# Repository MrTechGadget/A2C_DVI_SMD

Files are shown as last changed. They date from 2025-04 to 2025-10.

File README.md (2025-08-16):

# A2CDVI_SMD

This is a project for a digital DVI/HDMI video cards for Apple IIc or IIc+. It directly produces a digital video stream from the Apple IIc's digital video output connector. The signal is output via an HDMI connector, connecting the Apple IIc to modern displays with HDMI (or DVI) inputs. No more analog signal conversion required.

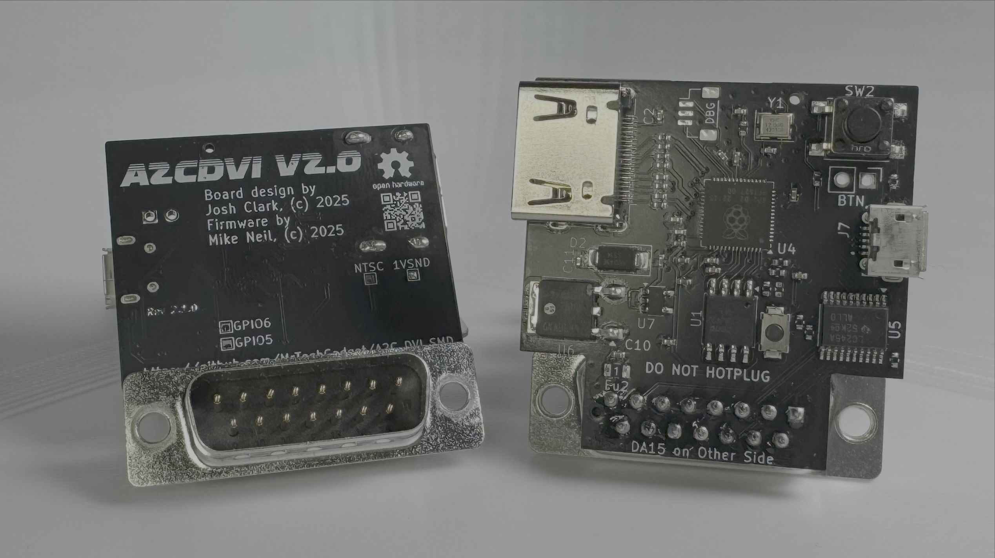
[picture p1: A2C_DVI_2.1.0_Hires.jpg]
A2CDVI v2.1.0 Board


## BACKGROUND
### Mike Neil's [Inspiration](https://github.com/FarLeftLane/A2C_DVI_Board)
> I have been working on a project using an ESP32-C6 to take the digital video signals from the Apple IIc DB15 video connector and allow remote viewing of the screen on a PC (watch this account for the ViewIIc plans).  The circuit design was pretty simple, a DB15 connector, a 74VLC245 for level conversion (5V to 3.3V) and a ESP32-C6 module. It occured to me that I could take those same Apple IIc signals and using the picoDVI libraries create a IIc to HDMI solution using an RP2040 or RP2350 (Raspberry Pi Pico). This is the same HW that is on an A2DVI card for a slotted Apple II (RP2040 and 245's). The Protype takes the A2DVI card out of the machine and instead of connecting to Apple II bus signals (address, data, etc), we feed the Apple IIc digital video signals into the cards pins and use custom firmware to recreate the display out to HDMI.

## HARDWARE
### Protoype

My first version was designed from Mike's schematic and mapping those through the the needed components found on the A2DVI card itself. It utilized a Raspberry Pi Pico device for simplicity, but the overall size was too big and it blocked access to the composite video

### Version 2

Inspired by the working prototype, I decided I could make it MUCH smaller by implementing the RP2040 directly on the board. 

### Version 2.5

Fixed compatibility issues with some HDTVs and added hardware support for Mike Neil's latest firmware features!

## Availability

This card is available for purchase in the US for $35 plus shipping on my Tindie Store [MrTechGadget's Gadgets](https://www.tindie.com/products/mrtechgadget/a2cdvi/)

## Flashing Firmware
The latest firmware can be found on Mike Neil's [A2C_DVI_Firmware repo](https://github.com/FarLeftLane/A2C_DVI_Firmware/tree/master/Releases)

To load the firmware use a microUSB cable to your PC/Mac with the A2CDVI card plugged into the Apple IIc. It is the exact same process as flashing a Raspberry Pi Pico. There is a small BOOTSEL button in the middle of the board close to the DA15 connector, above the word HOTPLUG.  Hold that button down, and while holding it, plug the USB cable into your PC/Mac.  You should see a volume appear on the PC/Mac.  Copy the "A2C_DVI_v1.7.6.uf2" file to this volume and the card should update and reboot.   If you have a HDMI monitor attached to the card, you should see the A2C_DVI splash screen.  Unplug the card from USB.  Never Hotplug the DA15 connector to the Apple IIc.

**SPECIAL THANKS**

- Mike Neil ( https://github.com/FarLeftLane/ )
- Ralle Palaveev ( https://github.com/rallepalaveev/A2DVI )
- Thorsten Brehm ( https://github.com/ThorstenBr/A2DVI-Firmware )
- David Kuder ( https://github.com/V2RetroComputing/analog )

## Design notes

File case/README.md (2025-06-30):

# Case for A2CDVI v2.0

Thanks to Javier Rivera at [8bitstuff.com](https://www.8bitstuff.com/) for this 3D print case design! Check out and purchase his wonderful creations there!

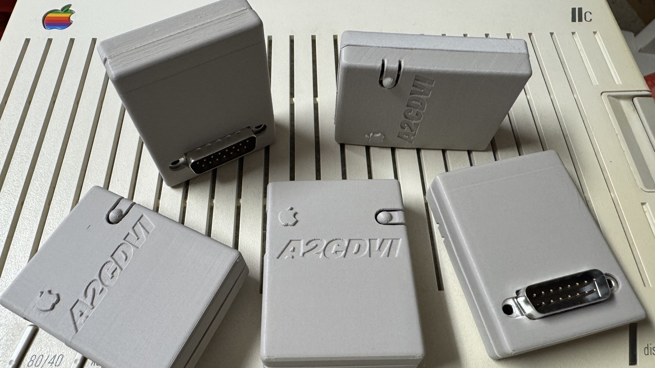
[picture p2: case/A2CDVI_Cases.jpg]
A2CDVI Cases


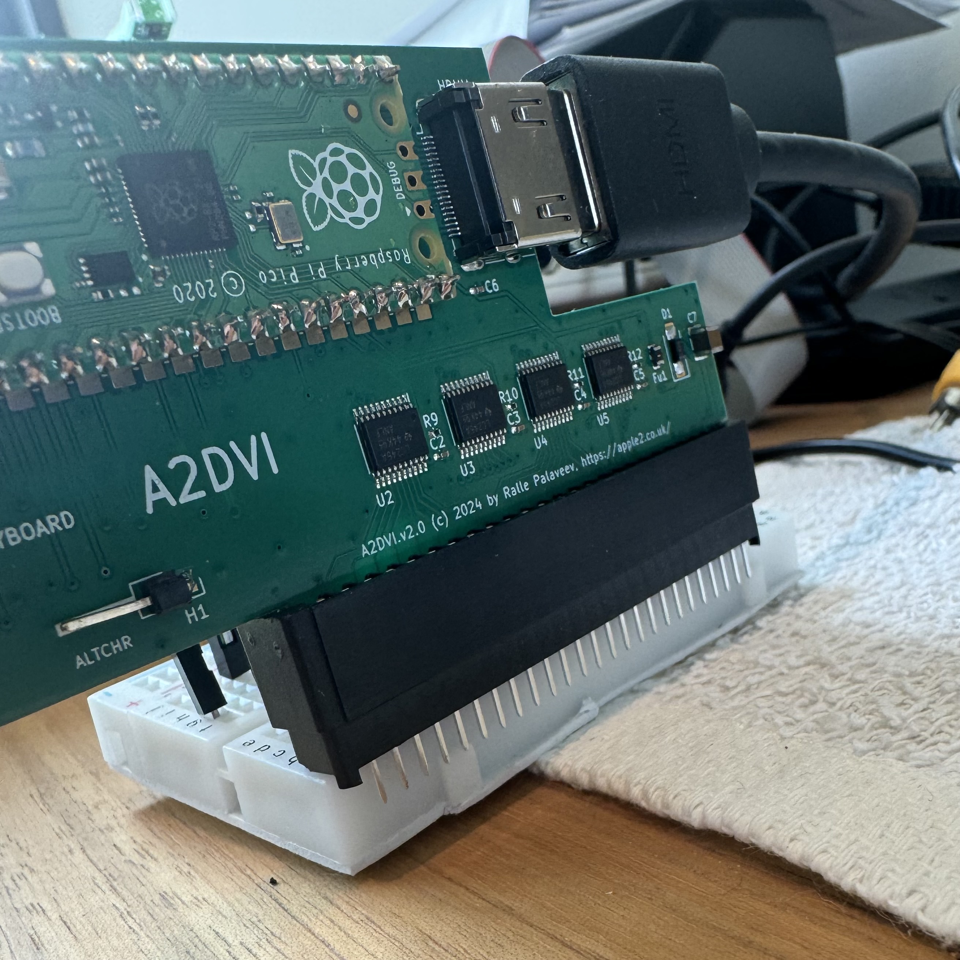
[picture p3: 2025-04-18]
434483009-aacbc47c-f8d5-4ea8-af98-b17cc606463b.jpg

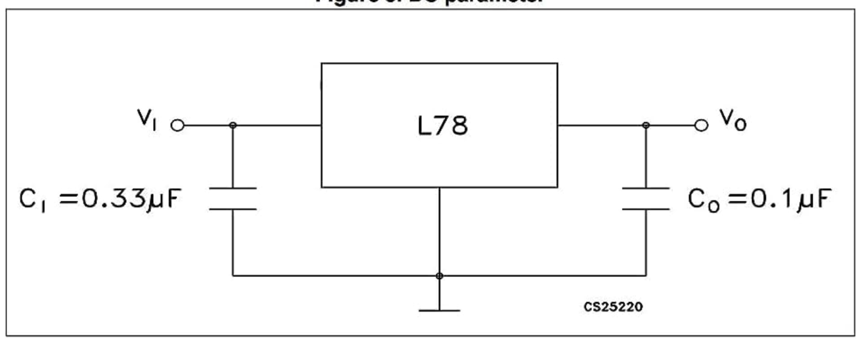
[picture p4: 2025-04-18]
434488253-ae684c7b-1a18-4d3e-9874-b82fae98b99a.png

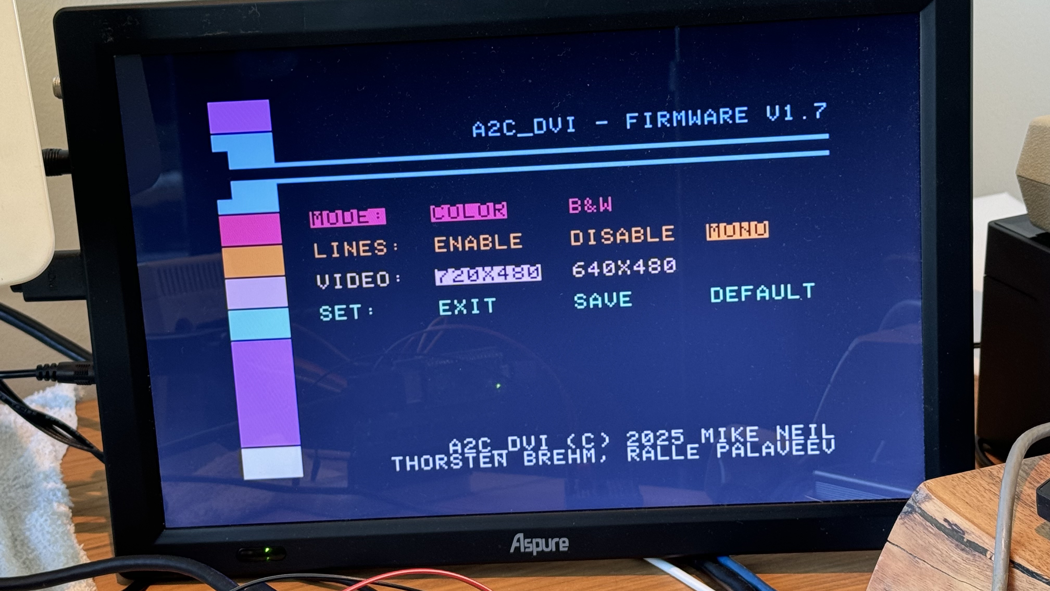
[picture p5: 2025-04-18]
434483163-00f029e0-050e-4da7-86ac-1dbc8562bdf5.jpg

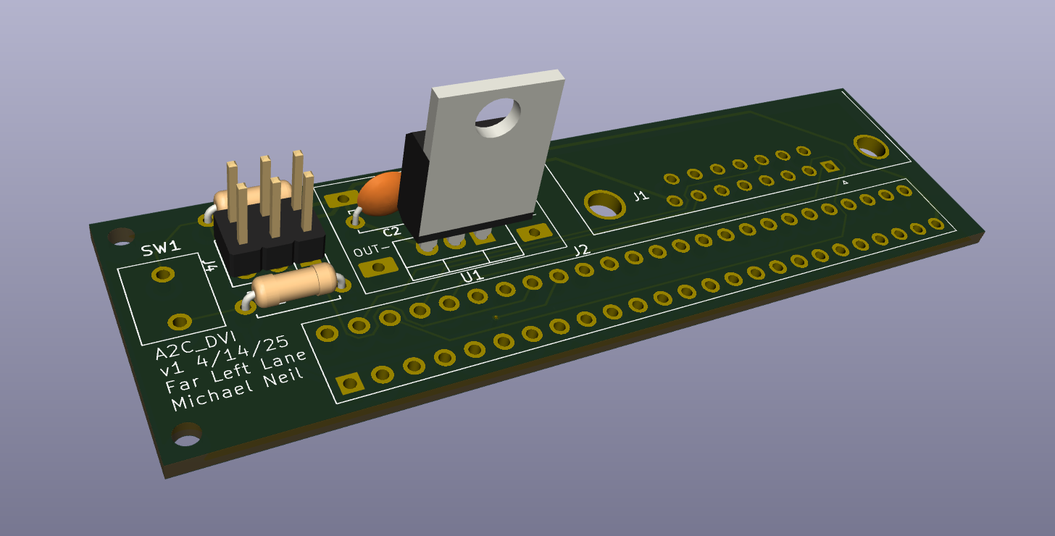
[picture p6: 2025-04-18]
434498170-325f45c0-930e-4e58-8a78-005b97d244a0.png

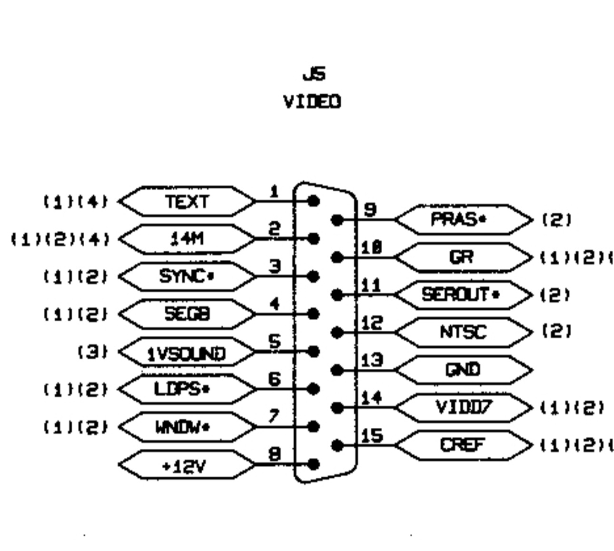
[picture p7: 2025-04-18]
434483400-4d250206-9c86-4687-9743-096d6ff55ef8.jpg

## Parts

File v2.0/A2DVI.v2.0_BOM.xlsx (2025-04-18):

Comment | Designator | Footprint | JLCPCB Part #（optional）
HDMI connector | HDMI1 |  | C7501808
PinHeader_1x01_P2.54mm_Horizontal | H1 |  | C2883838
270 | R1,R2,R3,R4,R5,R6,R7,R8 | 0402 | C25099
10k | R9,R10,R11,R12 | 0402 | C25744
16V 100nF X7R ±10% 0402 Multilayer Ceramic Capacitors MLCC - SMD/SMT ROHS | C1,C2,C3,C4,C5,C6 | 0402 | C1525
10V 100uF X5R ±20% 1210 Multilayer Ceramic Capacitors MLCC - SMD/SMT ROHS | C7 | 1210 | C386065
MBR120VLSFT1G | D1 | SOD123-FL | C223608
6V 100mA Resettable Fuse | Fu1 | 0805 | C20975
Raspberry Pi PICO | U1 |  | C7203002
SN74LVC245APWR | U2,U3,U4,U5 | TSSOP-20 | C7848

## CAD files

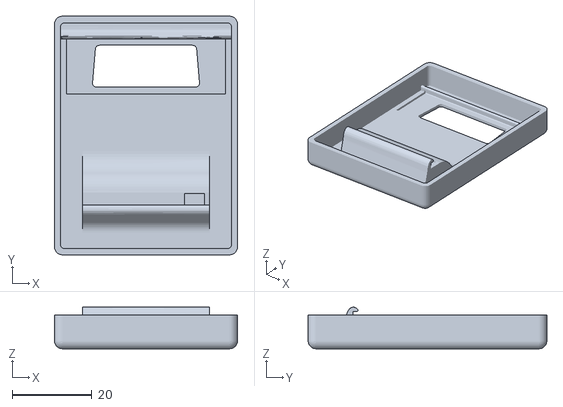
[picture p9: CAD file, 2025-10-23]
case/A2CDVI IIc Back -Joes Mod.stl
46.0 x 60.0 x 10.5

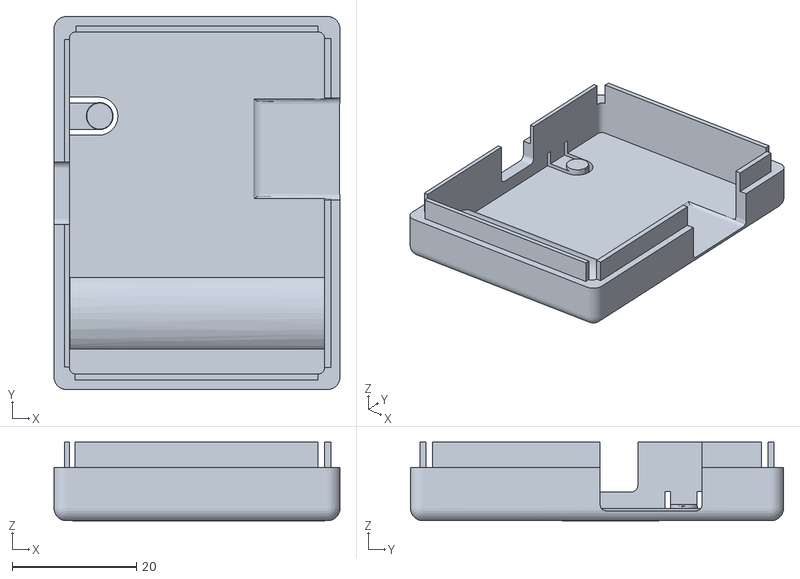
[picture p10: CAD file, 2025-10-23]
case/A2CDVI IIc Lid -NoText.stl
46.0 x 60.0 x 12.6

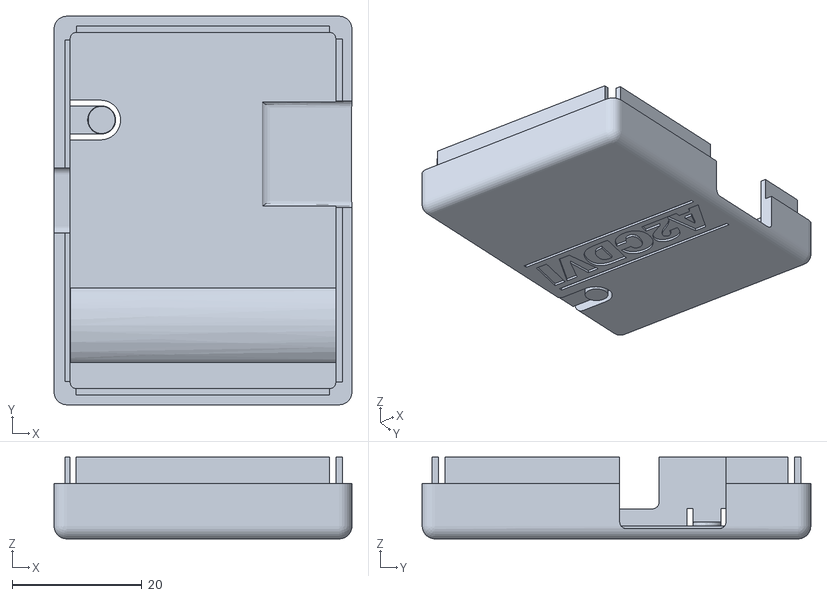
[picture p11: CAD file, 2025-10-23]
case/A2CDVI IIc Lid -Joes Mod.stl
46.0 x 60.0 x 12.6

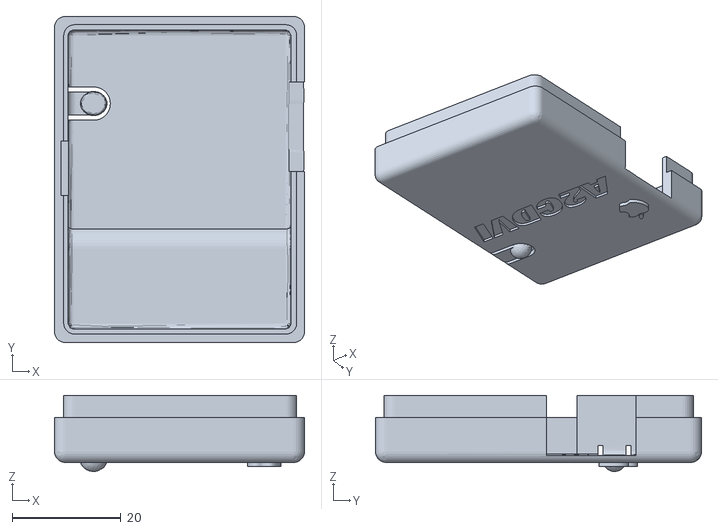
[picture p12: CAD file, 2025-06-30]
case/A2CDVI_IIc.stl
46.0 x 60.0 x 14.0

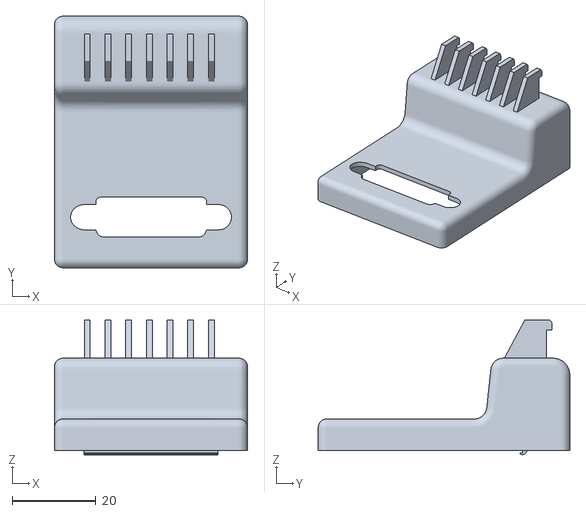
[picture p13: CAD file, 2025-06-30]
case/A2CDVI_IIc.fr.stl
46.0 x 60.0 x 32.1

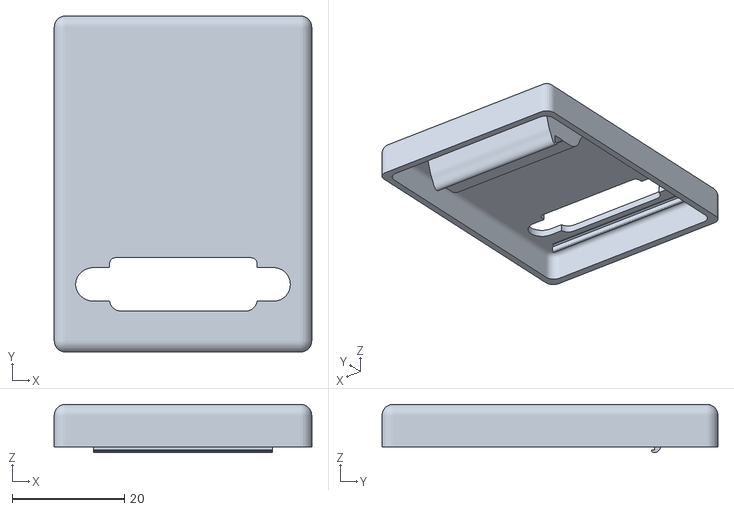
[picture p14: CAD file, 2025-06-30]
case/A2CDVI_IIc.FrSm.stl
46.0 x 60.0 x 8.64

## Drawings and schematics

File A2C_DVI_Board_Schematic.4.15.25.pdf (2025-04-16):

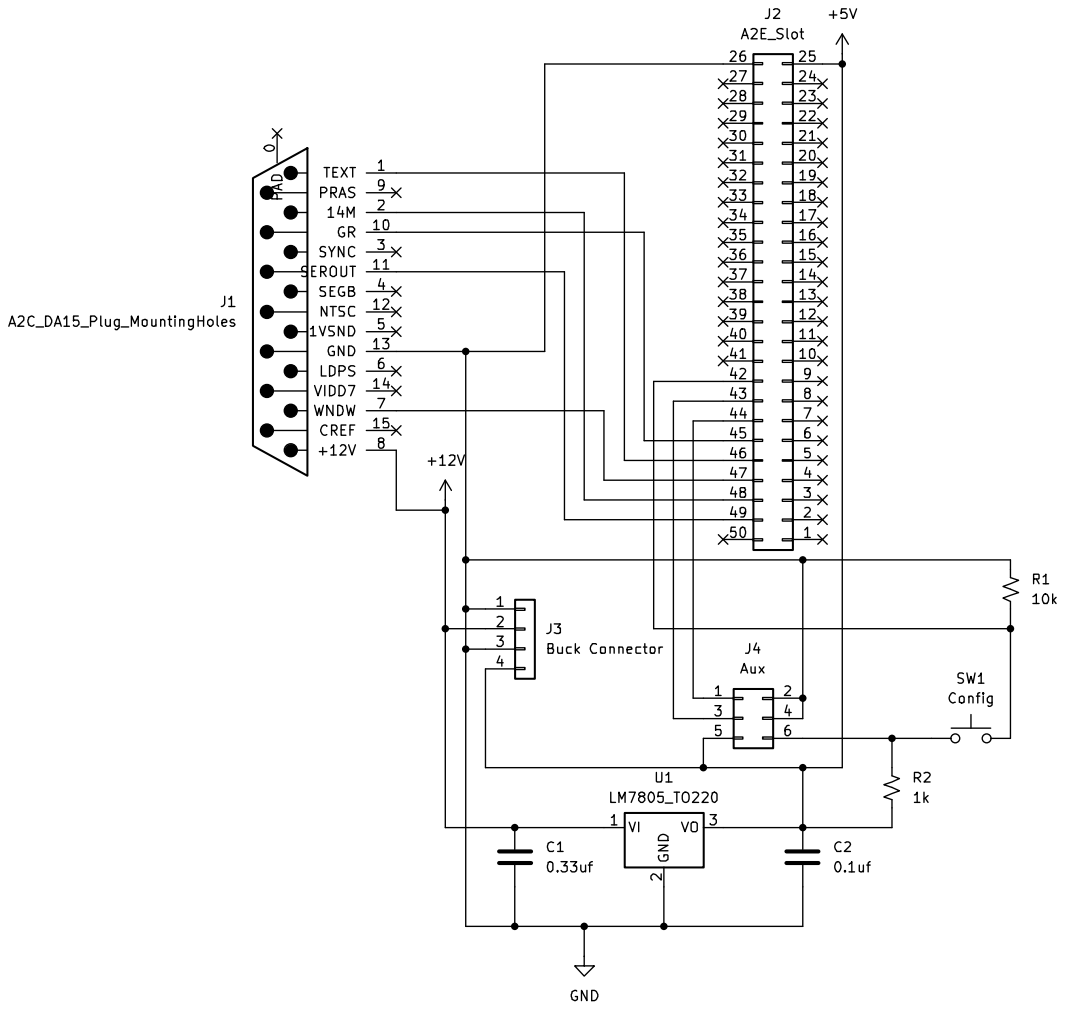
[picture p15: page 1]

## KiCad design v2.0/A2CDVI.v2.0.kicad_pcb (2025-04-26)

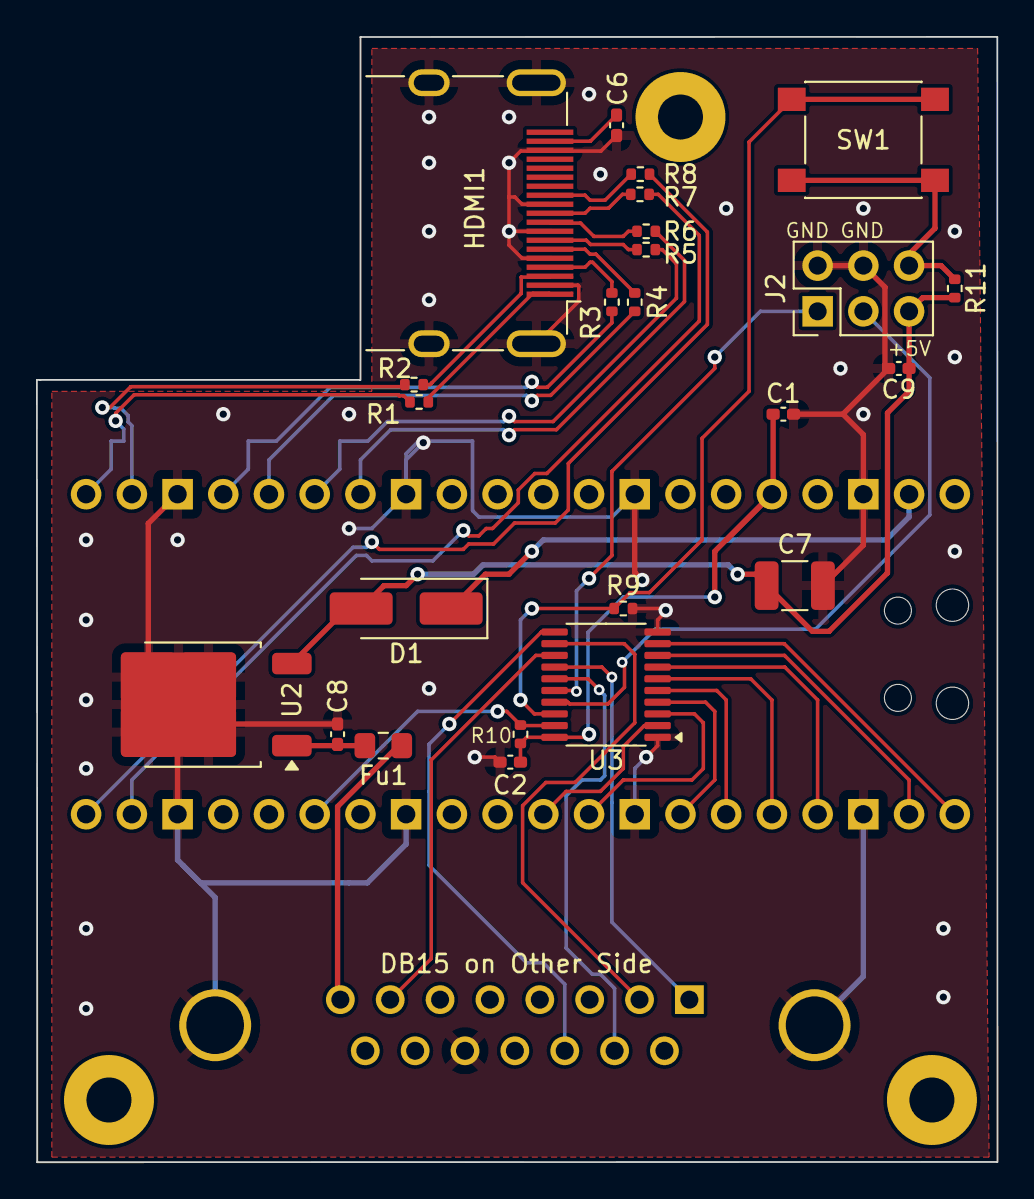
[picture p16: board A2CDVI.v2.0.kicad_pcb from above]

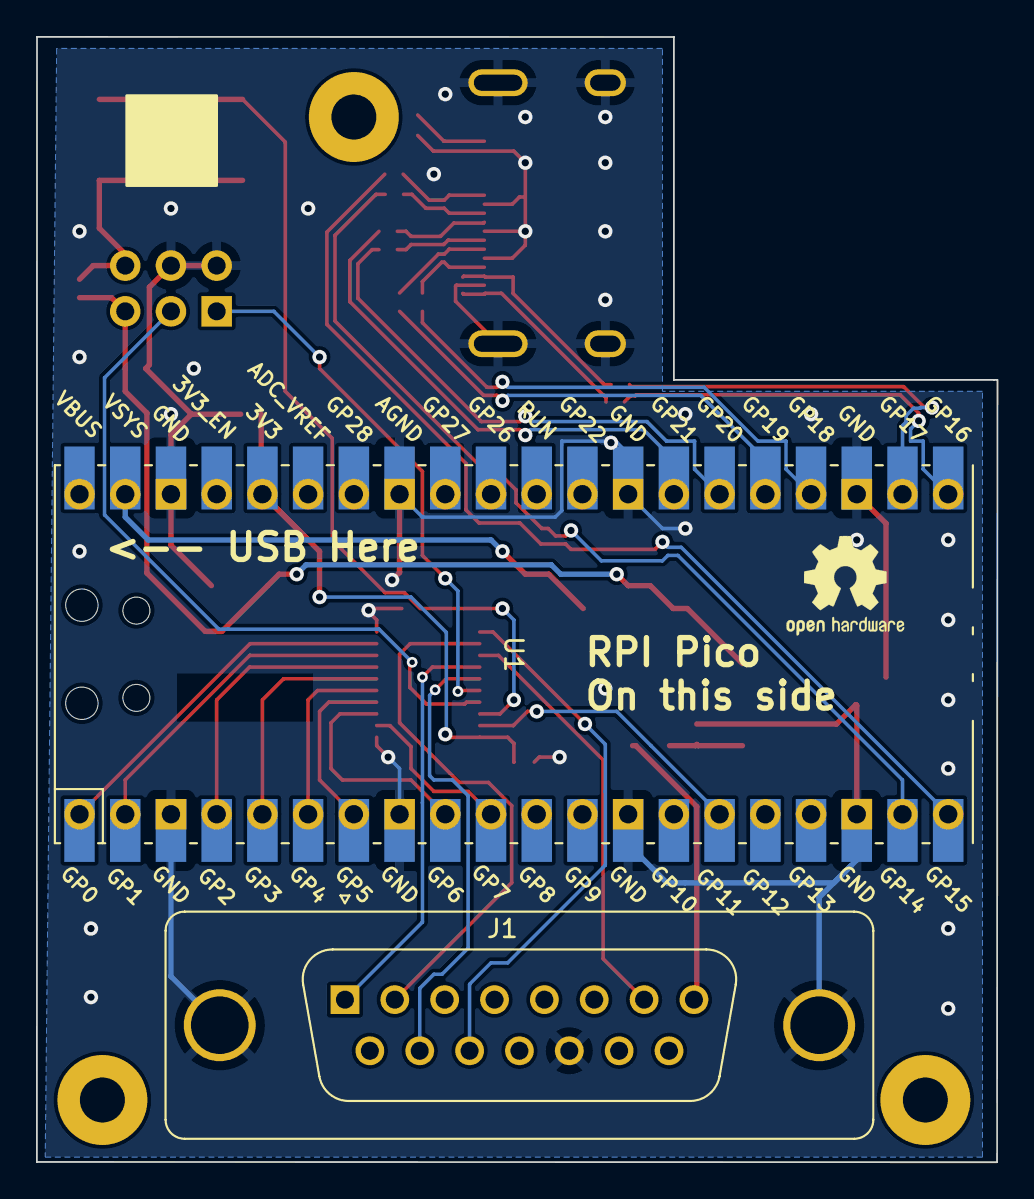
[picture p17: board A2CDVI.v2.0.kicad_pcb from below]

Board: 2 copper layers, 53.4 x 62.5 mm, 26 parts (2 on the bottom side), 33 nets.

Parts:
C1, C2, C6: 100n; C_0402_1005Metric_Pad0.74x0.62mm_HandSolder
C7: 220u; C_1210_3225Metric_Pad1.33x2.70mm_HandSolder
C8, C9: C; C_0402_1005Metric_Pad0.74x0.62mm_HandSolder
D1: MBR120VLSFT1G; D_SMA_Handsoldering
Fu1: Polyfuse 100mA; Fuse_0805_2012Metric_Pad1.15x1.40mm_HandSolder
HDMI1: HDMI-SWM-19; HDMI_A_Molex_208658-1001_Horizontal
J1: DA15_Plug; DSUB-15_Male_Vertical_P2.77x2.84mm_MountingHoles
J2: Aux; PinHeader_2x03_P2.54mm_Vertical
R1, R2, R3, R4, R5, R6, R7, R8: 270; R_0402_1005Metric
R9: 10k; R_0402_1005Metric
R10: 10K; R_0402_1005Metric
R11: 1k; R_0402_1005Metric
SW1: Config; SW_SPST_PTS645
U1: RPI-Pico; RPi_Pico_SMD_TH_NO_DEBUG
U2: L7805; TO-252-2
U3: 74LVC245; TSSOP-20_4.4x6.5mm_P0.65mm

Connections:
+3V3: C1.1, C2.1, R10.1, U1.36 (3V3), U3.20 (VCC)
+5V: C7.1, C9.1, D1.2 (A), J2.5, R11.2, U2.3 (OUT)
+12V: C8.1, Fu1.2, U2.1 (IN)
/CK+: HDMI1.10, R7.1, R7.2, U1.19 (GP14)
/CK-: HDMI1.12, R8.1, R8.2, U1.20 (GP15)
/D0+: HDMI1.7, R5.1, R5.2, U1.26 (GP20)
/D0-: HDMI1.9, R6.1, R6.2, U1.27 (GP21)
/D1+: HDMI1.4, R3.1, R3.2, U1.24 (GP18)
/D1-: HDMI1.6, R4.1, R4.2, U1.25 (GP19)
/D2+: HDMI1.1, R1.1, R1.2, U1.21 (GP16)
/D2-: HDMI1.3, R2.1, R2.2, U1.22 (GP17)
GND: C1.2, C2.2, C6.2, C7.2, C8.2, C9.2, HDMI1.2, HDMI1.5, HDMI1.8, HDMI1.11, HDMI1.17, HDMI1.GND, J1.0, J1.13 (GND), J2.2, J2.4, R9.2, U1.3 (GND), U1.8 (GND), U1.13 (GND), U1.18 (GND), U1.23 (GND), U1.28 (GND), U1.33 (GND), U1.38 (GND), U2.2 (GND), U3.1 (A->B), U3.10 (GND)
unnamed: C6.1, HDMI1.18
unnamed: D1.1 (K), U1.39 (VSYS)
unnamed: J1.2 (14M), U3.12 (B6)
unnamed: Fu1.1, J1.8 (+12V)
unnamed: J1.10 (GR), U3.15 (B3)
unnamed: J1.11 (SEROUT), U3.11 (B7)
unnamed: J1.1 (TEXT), U3.14 (B4)
unnamed: J1.7 (WNDW), U3.13 (B5)
unnamed: J2.1, U3.16 (B2)
unnamed: J2.3, U3.17 (B1)
unnamed: J2.6, R11.1, SW1.1
unnamed: U1.1 (GP0), U3.9 (A7)
unnamed: U1.2 (GP1), U3.8 (A6)
unnamed: U1.4 (GP2), U3.7 (A5)
unnamed: U1.5 (GP3), U3.6 (A4)
unnamed: U1.6 (GP4), U3.5 (A3)
unnamed: U1.7 (GP5), U3.4 (A2)
unnamed: U1.9 (GP6), U3.3 (A1)
unnamed: U1.10 (GP7), U3.2 (A0)
unnamed: R10.2, U1.15 (GP11), U3.19 (CE)
unnamed: R9.1, SW1.2, U3.18 (B0)

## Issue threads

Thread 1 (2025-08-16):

HDTV Compatibility - No Source Detected

MrTechGadget, 2025-08-16:
I got a report from a couple of users having issues connecting to HDTVs.

I did get a report of issue with some big modern HDTVs and not monitors.
It is a fairly simple bodge to get these TVs to recognize the signal.
Essentially, pin 18 of HDMI port needs +5 volts, easiest place to attach it is the bottom of the resistor next to the external button header (BTN) to the bottom of the C2 decoupling capacitor that goes to pin 18. See the red circles in the image below.

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

MrTechGadget, 2025-08-16:
This issue is resolved in the latest revision, v2.5. Any device sold by MrTechGadget on or after August 15th incorporates this fix.

MrTechGadget, 2025-08-16:
Here is another one fixed by Jeffery Lee

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

Closed 2025-08-17.

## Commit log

2025-04-18 Starting Schematic
    [A2CDVI.v2.0.kicad_pcb, A2CDVI.v2.0.kicad_sch, A2DVI.v2.0_BOM.xlsx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]
2025-04-18 Update A2CDVI.v2.0.kicad_sch
    Added components, removed Slot and extra 245 chips
    [A2CDVI.v2.0.kicad_sch]
2025-04-19 Initial Layout mess
    [A2CDVI.v2.0.kicad_pcb, A2CDVI.v2.0.kicad_sch]
2025-04-21 Basic Board Layout
    [A2CDVI.v2.0.kicad_pcb, A2CDVI.v2.0.kicad_sch]
2025-04-26 Tracks drawn
    [A2CDVI.v2.0.kicad_pcb, A2CDVI.v2.0.kicad_sch]
2025-04-26 Ready for v1
    [A2CDVI.v2.0.kicad_pcb]
2025-04-26 Fixed missing connections in schematic
    [A2CDVI.v2.0.kicad_pcb, A2CDVI.v2.0.kicad_sch]
2025-04-26 Fixed DRC issues
    [A2CDVI.v2.0.kicad_pcb]
2025-06-11 Add board image
2025-06-30 Added Case Files
    [A2CDVI_IIc.FrSm.stl, A2CDVI_IIc.fr.stl, A2CDVI_IIc.stl]
2025-10-23 Updated Case design for better connection
    This case is easier to print and has better retention in the DA15 video port on the Apple IIc
    [A2CDVI IIc Back -Joes Mod.stl, A2CDVI IIc Lid -Joes Mod.stl, A2CDVI IIc Lid -NoText.stl]

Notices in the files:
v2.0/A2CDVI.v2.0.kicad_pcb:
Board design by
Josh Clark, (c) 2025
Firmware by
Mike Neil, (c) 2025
